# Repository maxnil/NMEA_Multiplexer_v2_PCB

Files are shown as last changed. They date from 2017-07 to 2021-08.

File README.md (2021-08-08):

# NMEA_Multiplexer_v2_PCB
NMEA Multiplexer v2 PCB

Updated version of the old 2010 NMEA Miltiplexer.
This new improved version has support for 5 NMEA interfaces, USB as well as a BlueTooth module.

Firmware for this board is can be found in the https://github.com/maxnil/NMEA_Multiplexer_v2.0_FW repository.

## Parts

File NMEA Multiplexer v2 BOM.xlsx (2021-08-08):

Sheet: Sheet2
Reference | Value | Footprint | DigiKey part number
SW1 | Reset | Buttons_Switches_SMD:SW_SPST_EVQP2 | P12297SCT-ND (http://www.digikey.se/scripts/DkSearch/dksus.dll?Detail&itemSeq=233854998&uq=636362325610804098)
C1 | 0.1u | Capacitors_SMD:C_0603 | 1276-1006-1-ND (http://www.digikey.se/scripts/DkSearch/dksus.dll?Detail&itemSeq=233856982&uq=636362335538323001)
C2 | 0.1u | Capacitors_SMD:C_0603 | 1276-1006-1-ND (http://www.digikey.se/scripts/DkSearch/dksus.dll?Detail&itemSeq=233856982&uq=636362335538323001)
C3 | 0.1u | Capacitors_SMD:C_0603 | 1276-1006-1-ND
C4 | 0.1u | Capacitors_SMD:C_0603 | 1276-1006-1-ND
C5 | 0.1u | Capacitors_SMD:C_0603 | 1276-1006-1-ND
C6 | 0.1u | Capacitors_SMD:C_0603 | 1276-1006-1-ND
C9 | 0.1u | Capacitors_SMD:C_0603 | 1276-1006-1-ND
C10 | 0.1u | Capacitors_SMD:C_0603 | 1276-1006-1-ND
C12 | 0.1u | Capacitors_SMD:C_0603 | 1276-1006-1-ND
C13 | 0.1u | Capacitors_SMD:C_0603 | 1276-1006-1-ND
C15 | 0.1u | Capacitors_SMD:C_0603 | 1276-1006-1-ND
C16 | 0.1u | Capacitors_SMD:C_0603 | 1276-1006-1-ND
C17 | 0.1u | Capacitors_SMD:C_0603 | 1276-1006-1-ND
C18 | 0.1u | Capacitors_SMD:C_0603 | 1276-1006-1-ND
C19 | 0.1u | Capacitors_SMD:C_0603 | 1276-1006-1-ND
C20 | 0.1u | Capacitors_SMD:C_0603 | 1276-1006-1-ND
C21 | 0.1u | Capacitors_SMD:C_0603 | 1276-1006-1-ND
C22 | 0.1u | Capacitors_SMD:C_0603 | 1276-1006-1-ND
C24 | 0.1u | Capacitors_SMD:C_0603 | 1276-1006-1-ND
C26 | 0.1u | Capacitors_SMD:C_0603 | 1276-1006-1-ND
C27 | 0.1u | Capacitors_SMD:C_0603 | 1276-1006-1-ND
C28 | 0.1u | Capacitors_SMD:C_0603 | 1276-1006-1-ND
C29 | 0.1u | Capacitors_SMD:C_0603 | 1276-1006-1-ND
C25 | 2.2u | Capacitors_SMD:C_0603 | 399-7886-1-ND (http://www.digikey.se/scripts/DkSearch/dksus.dll?Detail&itemSeq=233857221&uq=636362336629405848)
C11 | 4.7u | Capacitors_SMD:C_0603 | 1276-1784-1-ND (http://www.digikey.se/scripts/DkSearch/dksus.dll?Detail&itemSeq=233857265&uq=636362336871900095)
C23 | 4.7u | Capacitors_SMD:C_0603 | 1276-1784-1-ND (http://www.digikey.se/scripts/DkSearch/dksus.dll?Detail&itemSeq=233857265&uq=636362336871900095)
C7 | 5p | Capacitors_SMD:C_0603 | 1276-2129-1-ND (http://www.digikey.se/scripts/DkSearch/dksus.dll?Detail&itemSeq=233856961&uq=636362335538313000)
C8 | 5p | Capacitors_SMD:C_0603 | 1276-2129-1-ND (http://www.digikey.se/scripts/DkSearch/dksus.dll?Detail&itemSeq=233856961&uq=636362335538313000)
C14 | 10u | Capacitors_SMD:CP_Elec_4x5.8 | 399-6695-1-ND (http://www.digikey.se/scripts/DkSearch/dksus.dll?Detail&itemSeq=233860772&uq=636362360830165682)
J7 | 12V | Connectors_Terminal_Blocks:TerminalBlock_Pheonix_PT-3.5mm_2pol | ED2740-ND (http://www.digikey.se/scripts/DkSearch/dksus.dll?Detail&itemSeq=233937810&uq=636364126030926649)
J2 | Port 1 | Connectors_Terminal_Blocks:TerminalBlock_Pheonix_PT-3.5mm_3pol | ED2741-ND (http://www.digikey.se/scripts/DkSearch/dksus.dll?Detail&itemSeq=233937812&uq=636364126030936651)
J3 | Port 2 | Connectors_Terminal_Blocks:TerminalBlock_Pheonix_PT-3.5mm_3pol | ED2741-ND (http://www.digikey.se/scripts/DkSearch/dksus.dll?Detail&itemSeq=233937812&uq=636364126030936651)
J4 | Port 3 | Connectors_Terminal_Blocks:TerminalBlock_Pheonix_PT-3.5mm_3pol | ED2741-ND (http://www.digikey.se/scripts/DkSearch/dksus.dll?Detail&itemSeq=233937812&uq=636364126030936651)
J5 | Port 4 | Connectors_Terminal_Blocks:TerminalBlock_Pheonix_PT-3.5mm_3pol | ED2741-ND (http://www.digikey.se/scripts/DkSearch/dksus.dll?Detail&itemSeq=233937812&uq=636364126030936651)
J6 | Port 5 | Connectors_Terminal_Blocks:TerminalBlock_Pheonix_PT-3.5mm_3pol | ED2741-ND (http://www.digikey.se/scripts/DkSearch/dksus.dll?Detail&itemSeq=233937812&uq=636364126030936651)
J1 | USB | Connectors:USB_Mini-B | H2959CT-ND (http://www.digikey.se/scripts/DkSearch/dksus.dll?Detail&itemSeq=233838959&uq=636362305705239991)
Y1 | 32.768k | Crystals:Crystal_SMD_3215-2pin_3.2x1.5mm | 631-1002-1-ND (http://www.digikey.se/scripts/DkSearch/dksus.dll?Detail&itemSeq=233862150&uq=636362369648505753)
U2 | XR32330 | Housings_DFN_QFN:QFN-24_4x4mm_Pitch0.5mm_NoMask | 1016-2177-ND (http://www.digikey.se/scripts/DkSearch/dksus.dll?Detail&itemSeq=233859401&uq=636362352373879101)
U3 | XR32330 | Housings_DFN_QFN:QFN-24_4x4mm_Pitch0.5mm_NoMask | 1016-2177-ND (http://www.digikey.se/scripts/DkSearch/dksus.dll?Detail&itemSeq=233859401&uq=636362352373879101)
U1 | ATSAMG55J19A-AU | Housings_QFP:LQFP-64_10x10mm_Pitch0.5mm | 1611-ATSAMG55J19A-AUTCT-ND (http://www.digikey.se/scripts/DkSearch/dksus.dll?Detail&itemSeq=233859668&uq=636362353992571220)
D8 | BT Con (blue) | LEDs:LED_0603 | 475-2815-1-ND (http://www.digikey.se/scripts/DkSearch/dksus.dll?Detail&itemSeq=233851496&uq=636362305705279995)
D18 | Err 0 (red) | LEDs:LED_0603 | 511-1586-1-ND (http://www.digikey.se/scripts/DkSearch/dksus.dll?Detail&itemSeq=233851438&uq=636362305705259993)
D15 | Err 1 (red) | LEDs:LED_0603 | 511-1586-1-ND (http://www.digikey.se/scripts/DkSearch/dksus.dll?Detail&itemSeq=233851438&uq=636362305705259993)
D12 | Err 2 (red) | LEDs:LED_0603 | 511-1586-1-ND (http://www.digikey.se/scripts/DkSearch/dksus.dll?Detail&itemSeq=233851438&uq=636362305705259993)
D2 | Err 3 (red) | LEDs:LED_0603 | 511-1586-1-ND
D5 | Err 4 (red) | LEDs:LED_0603 | 511-1586-1-ND
D7 | PWR (white) | LEDs:LED_0603 | 511-1602-1-ND (http://www.digikey.se/scripts/DkSearch/dksus.dll?Detail&itemSeq=233851586&uq=636362305705289996)
D19 | Rx 0 (green) | LEDs:LED_0603 | 511-1584-1-ND (http://www.digikey.se/scripts/DkSearch/dksus.dll?Detail&itemSeq=233851423&uq=636362305705249992)
D16 | Rx 1 (green) | LEDs:LED_0603 | 511-1584-1-ND (http://www.digikey.se/scripts/DkSearch/dksus.dll?Detail&itemSeq=233851423&uq=636362305705249992)
D13 | Rx 2 (green) | LEDs:LED_0603 | 511-1584-1-ND
D3 | Rx 3 (green) | LEDs:LED_0603 | 511-1584-1-ND
D6 | Rx 4 (green) | LEDs:LED_0603 | 511-1584-1-ND
D10 | Rx BT (green) | LEDs:LED_0603 | 511-1584-1-ND
D11 | Tx (green) | LEDs:LED_0603 | 511-1584-1-ND
D17 | Tx 0 (green) | LEDs:LED_0603 | 511-1584-1-ND
D14 | Tx 1 (green) | LEDs:LED_0603 | 511-1584-1-ND
D1 | Tx 3 (green) | LEDs:LED_0603 | 511-1584-1-ND
D4 | Tx 4 (green) | LEDs:LED_0603 | 511-1584-1-ND
D9 | Tx BT (green) | LEDs:LED_0603 | 511-1584-1-ND
U5 | HM-11 | MaxNil:HM-11 | n/a
JP1 | ERASE | Pin_Headers:Pin_Header_Straight_1x02_Pitch2.00mm | 952-2326-ND (http://www.digikey.se/scripts/DkSearch/dksus.dll?Detail&itemSeq=233938101&uq=636364129656245809)
J8 | DEBUG UART | Pin_Headers:Pin_Header_Straight_1x03_Pitch2.54mm | S1011EC-40-ND (http://www.digikey.se/scripts/DkSearch/dksus.dll?Detail&itemSeq=233938745&uq=636364143898009148)
J9 | JTAG | Pin_Headers:Pin_Header_Straight_2x05_Pitch1.27mm_SMD | 609-3741-ND (http://www.digikey.se/scripts/DkSearch/dksus.dll?Detail&itemSeq=233858132&uq=636362343783641200)
R10 | 39 | Resistors_SMD:R_0603 | 311-39.0HRCT-ND (http://www.digikey.se/scripts/DkSearch/dksus.dll?Detail&itemSeq=233862991&uq=636362373801941220)
R12 | 39 | Resistors_SMD:R_0603 | 311-39.0HRCT-ND (http://www.digikey.se/scripts/DkSearch/dksus.dll?Detail&itemSeq=233862991&uq=636362373801941220)
R16 | 39 | Resistors_SMD:R_0603 | 311-39.0HRCT-ND (http://www.digikey.se/scripts/DkSearch/dksus.dll?Detail&itemSeq=233862991&uq=636362373801941220)
R17 | 39 | Resistors_SMD:R_0603 | 311-39.0HRCT-ND (http://www.digikey.se/scripts/DkSearch/dksus.dll?Detail&itemSeq=233862991&uq=636362373801941220)
R13 | 120 | Resistors_SMD:R_0603
R1 | 220 | Resistors_SMD:R_0603 | 311-220HRCT-ND (http://www.digikey.se/scripts/DkSearch/dksus.dll?Detail&itemSeq=233862888&uq=636362373801931220)
R2 | 220 | Resistors_SMD:R_0603 | 311-220HRCT-ND
R3 | 220 | Resistors_SMD:R_0603 | 311-220HRCT-ND
R4 | 220 | Resistors_SMD:R_0603 | 311-220HRCT-ND
R5 | 220 | Resistors_SMD:R_0603 | 311-220HRCT-ND
R6 | 220 | Resistors_SMD:R_0603 | 311-220HRCT-ND
R7 | 220 | Resistors_SMD:R_0603 | 311-220HRCT-ND
R8 | 220 | Resistors_SMD:R_0603 | 311-220HRCT-ND
R18 | 220 | Resistors_SMD:R_0603 | 311-220HRCT-ND
R19 | 220 | Resistors_SMD:R_0603 | 311-220HRCT-ND
R20 | 220 | Resistors_SMD:R_0603 | 311-220HRCT-ND
R21 | 220 | Resistors_SMD:R_0603 | 311-220HRCT-ND
R22 | 220 | Resistors_SMD:R_0603 | 311-220HRCT-ND
R23 | 220 | Resistors_SMD:R_0603 | 311-220HRCT-ND
R27 | 220 | Resistors_SMD:R_0603 | 311-220HRCT-ND
R28 | 220 | Resistors_SMD:R_0603 | 311-220HRCT-ND
R29 | 220 | Resistors_SMD:R_0603 | 311-220HRCT-ND
R9 | 82 | Resistors_SMD:R_0603 | 311-82.0HRCT-ND (http://www.digikey.se/scripts/DkSearch/dksus.dll?Detail&itemSeq=233862972&uq=636362373801931220)
R11 | 100k | Resistors_SMD:R_0603 | 311-100KHRCT-ND (http://www.digikey.se/scripts/DkSearch/dksus.dll?Detail&itemSeq=233862853&uq=636362373801921220)
R24 | 100k | Resistors_SMD:R_0603 | 311-100KHRCT-ND (http://www.digikey.se/scripts/DkSearch/dksus.dll?Detail&itemSeq=233862853&uq=636362373801921220)
R25 | 100k | Resistors_SMD:R_0603 | 311-100KHRCT-ND
R26 | 100k | Resistors_SMD:R_0603 | 311-100KHRCT-ND
R14 | 27k | Resistors_SMD:R_0603 | 311-27.0KHRCT-ND (http://www.digikey.se/scripts/DkSearch/dksus.dll?Detail&itemSeq=233862921&uq=636362373801931220)
R15 | 47k | Resistors_SMD:R_0603 | 311-47.0KHRCT-ND (http://www.digikey.se/scripts/DkSearch/dksus.dll?Detail&itemSeq=233862873&uq=636362373801921220)
U4 | LF33ABDT-TR | TO_SOT_Packages_SMD:TO-252-2_Rectifier | 497-5225-1-ND (http://www.digikey.se/scripts/DkSearch/dksus.dll?Detail&itemSeq=233863143&uq=636362374865240887)

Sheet: Sheet1
Reference | Value | Footprint | Datasheet
U1 | ATSAMG55J19A-AU | Housings_QFP:LQFP-64_10x10mm_Pitch0.5mm
Y1 | 32.768k | Crystals:Crystal_SMD_3215-2pin_3.2x1.5mm
C8 | 5n | Capacitors_SMD:C_0603
C7 | 5n | Capacitors_SMD:C_0603
J1 | USB | Connectors:USB_Mini-B
J9 | JTAG | Pin_Headers:Pin_Header_Straight_2x05_Pitch1.27mm_SMD
R24 | 100k | Resistors_SMD:R_0603
R25 | 100k | Resistors_SMD:R_0603
R26 | 100k | Resistors_SMD:R_0603
JP1 | ERASE | Pin_Headers:Pin_Header_Straight_1x02_Pitch2.00mm
R16 | 39 | Resistors_SMD:R_0603
R17 | 39 | Resistors_SMD:R_0603
D18 | Err 0 (red) | LEDs:LED_0603
R27 | 220 | Resistors_SMD:R_0603
R28 | 220 | Resistors_SMD:R_0603
R29 | 220 | Resistors_SMD:R_0603
D17 | Tx 0 (green) | LEDs:LED_0603
D19 | Rx 0 (green) | LEDs:LED_0603
D15 | Err 1 (red) | LEDs:LED_0603
R21 | 220 | Resistors_SMD:R_0603
R23 | 220 | Resistors_SMD:R_0603
R22 | 220 | Resistors_SMD:R_0603
D14 | Tx 1 (green) | LEDs:LED_0603
D16 | Rx 1 (green) | LEDs:LED_0603
D12 | Err 2 (red) | LEDs:LED_0603
R19 | 220 | Resistors_SMD:R_0603
R18 | 220 | Resistors_SMD:R_0603
R20 | 220 | Resistors_SMD:R_0603
D11 | Tx (green) | LEDs:LED_0603
D13 | Rx 2 (green) | LEDs:LED_0603
D2 | Err 3 (red) | LEDs:LED_0603
R1 | 220 | Resistors_SMD:R_0603
R3 | 220 | Resistors_SMD:R_0603
R2 | 220 | Resistors_SMD:R_0603
D1 | Tx 3 (green) | LEDs:LED_0603
D3 | Rx 3 (green) | LEDs:LED_0603
D5 | Err 4 (red) | LEDs:LED_0603
R5 | 220 | Resistors_SMD:R_0603
R4 | 220 | Resistors_SMD:R_0603
R6 | 220 | Resistors_SMD:R_0603
D4 | Tx 4 (green) | LEDs:LED_0603
D6 | Rx 4 (green) | LEDs:LED_0603
R7 | 220 | Resistors_SMD:R_0603
R8 | 220 | Resistors_SMD:R_0603
D9 | Tx BT (green) | LEDs:LED_0603
D10 | Rx BT (green) | LEDs:LED_0603
D8 | BT Con (blue) | LEDs:LED_0603
R13 | 220 | Resistors_SMD:R_0603
J8 | DEBUG UART | Pin_Headers:Pin_Header_Straight_1x03_Pitch2.54mm
D7 | PWR (green) | LEDs:LED_0603
R9 | 220 | Resistors_SMD:R_0603
R14 | 27k | Resistors_SMD:R_0603
R15 | 47k | Resistors_SMD:R_0603
SW1 | Reset | Buttons_Switches_SMD:SW_SPST_EVQP2
R12 | 39 | Resistors_SMD:R_0603
R10 | 39 | Resistors_SMD:R_0603
R11 | 100k | Resistors_SMD:R_0603
U3 | XR32330 | Housings_DFN_QFN:QFN-24_4x4mm_Pitch0.5mm_NoMask
U2 | XR32330 | Housings_DFN_QFN:QFN-24_4x4mm_Pitch0.5mm_NoMask
J2 | Port 1 | Connectors_Terminal_Blocks:TerminalBlock_Pheonix_PT-3.5mm_3pol
J3 | Port 2 | Connectors_Terminal_Blocks:TerminalBlock_Pheonix_PT-3.5mm_3pol
J4 | Port 3 | Connectors_Terminal_Blocks:TerminalBlock_Pheonix_PT-3.5mm_3pol
J5 | Port 4 | Connectors_Terminal_Blocks:TerminalBlock_Pheonix_PT-3.5mm_3pol
J6 | Port 5 | Connectors_Terminal_Blocks:TerminalBlock_Pheonix_PT-3.5mm_3pol
J7 | 12V | Connectors_Terminal_Blocks:TerminalBlock_Pheonix_PT-3.5mm_2pol
U4 | LF33ABDT-TR | TO_SOT_Packages_SMD:TO-252-2_Rectifier
C14 | 10u | Capacitors_SMD:CP_Elec_4x5.8
C15 | 100n | Capacitors_SMD:C_0603
C13 | 100n | Capacitors_SMD:C_0603
C29 | 100n | Capacitors_SMD:C_0603
C9 | 100n | Capacitors_SMD:C_0603
C25 | 2.2u | Capacitors_SMD:C_0603
C26 | 100n | Capacitors_SMD:C_0603
C23 | 4.7u | Capacitors_SMD:C_0603
C24 | 100n | Capacitors_SMD:C_0603
C12 | 100n | Capacitors_SMD:C_0603
C11 | 4.7u | Capacitors_SMD:C_0603
C10 | 100n | Capacitors_SMD:C_0603
C27 | 100n | Capacitors_SMD:C_0603
C28 | 100n | Capacitors_SMD:C_0603
C22 | 100n | Capacitors_SMD:C_0603
U5 | HM-11 | MaxNil:HM-11
C1 | 100n | Capacitors_SMD:C_0603
C2 | 100n | Capacitors_SMD:C_0603
C16 | 100n | Capacitors_SMD:C_0603
C17 | 100n | Capacitors_SMD:C_0603
C6 | 100n | Capacitors_SMD:C_0603
C4 | 100n | Capacitors_SMD:C_0603
C3 | 100n | Capacitors_SMD:C_0603
C5 | 100n | Capacitors_SMD:C_0603
C21 | 100n | Capacitors_SMD:C_0603
C19 | 100n | Capacitors_SMD:C_0603
C18 | 100n | Capacitors_SMD:C_0603
C20 | 100n | Capacitors_SMD:C_0603

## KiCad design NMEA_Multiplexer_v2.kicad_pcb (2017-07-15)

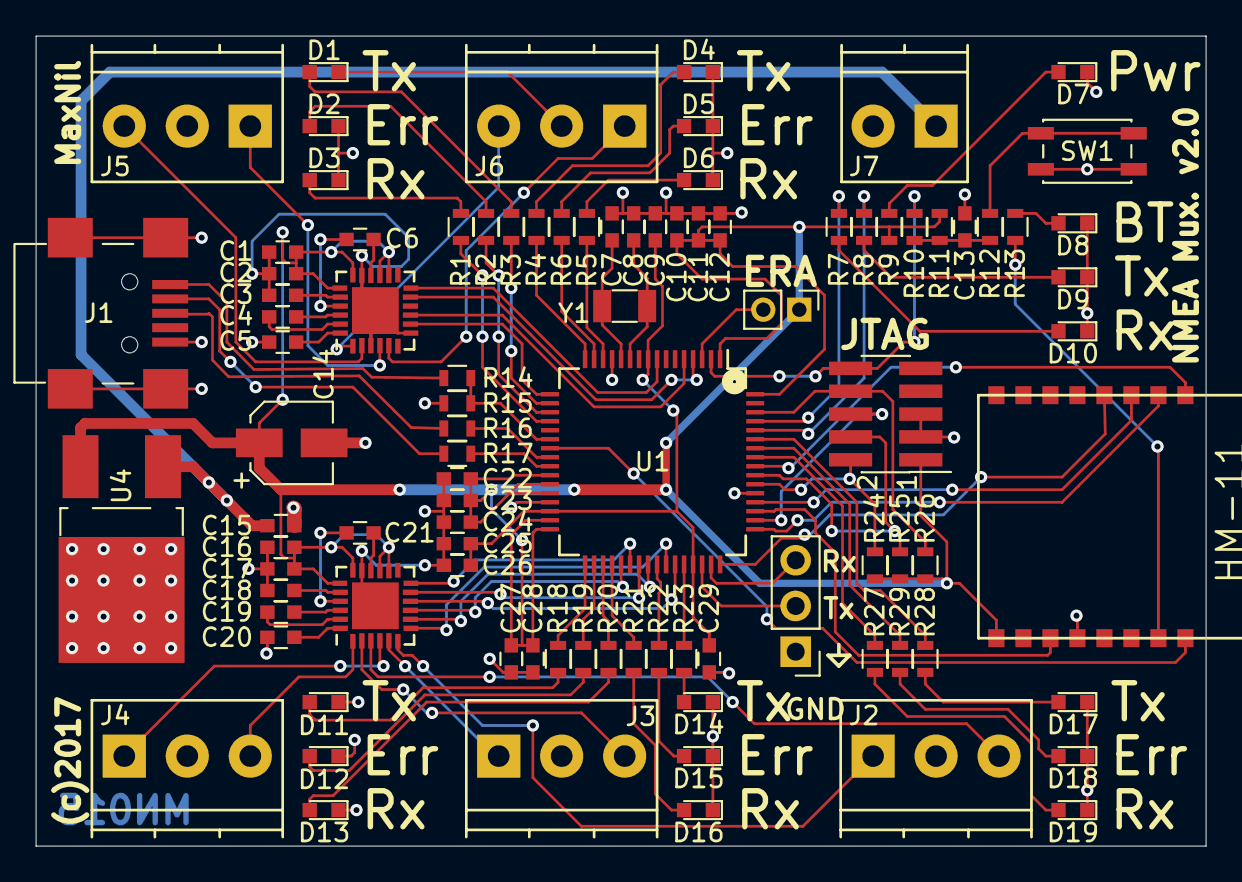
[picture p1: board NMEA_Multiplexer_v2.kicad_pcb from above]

Board: 2 copper layers, 65.0 x 45.0 mm, 94 parts (0 on the bottom side), 97 nets.

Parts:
C1, C2, C3, C4, C5, C6, C9, C10, C12, C13, C15, C16, C17, C18, C19, C20, C21, C22, C24, C26, C27, C28, C29: 100n; C_0603
C7, C8: 5n; C_0603
C11, C23: 4.7u; C_0603
C14: 10u; CP_Elec_4x5.8
C25: 2.2u; C_0603
D1: Tx 3 (green); LED_0603
D2: Err 3 (red); LED_0603
D3: Rx 3 (green); LED_0603
D4: Tx 4 (green); LED_0603
D5: Err 4 (red); LED_0603
D6: Rx 4 (green); LED_0603
D7: PWR (green); LED_0603
D8: BT Con (blue); LED_0603
D9: Tx BT (green); LED_0603
D10: Rx BT (green); LED_0603
D11: Tx (green); LED_0603
D12: Err 2 (red); LED_0603
D13: Rx 2 (green); LED_0603
D14: Tx 1 (green); LED_0603
D15: Err 1 (red); LED_0603
D16: Rx 1 (green); LED_0603
D17: Tx 0 (green); LED_0603
D18: Err 0 (red); LED_0603
D19: Rx 0 (green); LED_0603
J1: USB; USB_Mini-B_UX60-MB-5ST
J2: Port 1; TerminalBlock_Pheonix_PT-3.5mm_3pol
J3: Port 2; TerminalBlock_Pheonix_PT-3.5mm_3pol
J4: Port 3; TerminalBlock_Pheonix_PT-3.5mm_3pol
J5: Port 4; TerminalBlock_Pheonix_PT-3.5mm_3pol
J6: Port 5; TerminalBlock_Pheonix_PT-3.5mm_3pol
J7: 12V; TerminalBlock_Pheonix_PT-3.5mm_2pol
J8: DEBUG UART; Pin_Header_Straight_1x03_Pitch2.54mm
J9: JTAG; Pin_Header_Straight_2x05_Pitch1.27mm_SMD
JP1: ERASE; Pin_Header_Straight_1x02_Pitch2.00mm
R1, R2, R3, R4, R5, R6, R7, R8, R9, R13, R18, R19, R20, R21, R22, R23, R27, R28, R29: 220; R_0603
R10, R12, R16, R17: 39; R_0603
R11, R24, R25, R26: 100k; R_0603
R14: 27k; R_0603
R15: 47k; R_0603
SW1: Reset; SW_SPST_EVQP2
U1: ATSAMG55J19A-AU; LQFP-64_10x10mm_Pitch0.5mm
U2, U3: XR32330; QFN-24_4x4mm_Pitch0.5mm_NoMask
U4: LF33ABDT-TR; TO-252-2_Rectifier
U5: HM-11
Y1: 32.768k; Crystal_SMD_3215-2pin_3.2x1.5mm

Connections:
+1V8: C9.1, C25.1, C26.1, C29.1, U1.9, U1.30, U1.45
+3V3: C1.1, C2.1, C10.1, C11.1, C12.1, C14.1, C16.1, C17.1, C22.1, C23.1, C24.1, C27.1, C28.1, J9.1, JP1.1, R9.1, R11.1, R24.1, R25.1, R26.1, U1.1, U1.26, U1.27, U1.28, U1.31, U1.32, U1.64, U2.14, U2.15, U2.18, U2.19, U3.14, U3.15, U3.18, U3.19, U4.3, U5.9
/BT_KEY: U1.23, U5.16
/BT_RESET_N: U1.51, U5.11
/CTS0: U1.56, U5.1
/DM: R17.1, U1.25
/DP: R16.1, U1.24
/LED_0_ERR: R29.1, U1.58
/LED_0_RX: R27.1, U1.57
/LED_0_TX: R28.1, U1.59
/LED_1_ERR: R22.1, U1.41
/LED_1_RX: R21.1, U1.36
/LED_1_TX: R23.1, U1.44
/LED_2_ERR: R19.1, U1.34
/LED_2_RX: R20.1, U1.35
/LED_2_TX: R18.1, U1.33
/LED_3_ERR: R2.1, U1.19
/LED_3_RX: R1.1, U1.20
/LED_3_TX: R3.1, U1.18
/LED_4_ERR: R6.1, U1.15
/LED_4_RX: R5.1, U1.14
/LED_4_TX: R4.1, U1.16
/LED_BT_CON: R13.1, U5.15
/LED_BT_RX: R7.1, U1.61
/LED_BT_TX: R8.1, U1.60
/RTS0: U1.52, U5.3
/RX0: J2.3, U3.3
/RX1: J3.3, U3.2
/RX2: J4.3, U3.1
/RX3: J5.3, U2.2
/RX4: J6.3, U2.1
/RXD0: U1.49, U5.2
/RXD1: U1.39, U3.11
/RXD2: U1.8, U2.12
/RXD3: U1.4, U2.11
/RXD4: J8.3, U1.47
/RXD5: U1.43, U3.10
/RXD6: U1.38, U3.12
/TCK: J9.4, R25.2, U1.55
/TDI: J9.8, R26.2, U1.62
/TDO: J9.6, U1.50
/TMS: J9.2, R24.2, U1.54
/TX0: J2.1, U3.6
/TX1: J3.1, U3.5
/TX2: J4.1, U3.4
/TX3: J5.1, U2.4
/TX4: J6.1, U2.5
/TXD0: U1.48, U5.4
/TXD1: U1.40, U3.8
/TXD2: U1.17, U2.8
/TXD3: U1.5, U2.9
/TXD4: J8.2, U1.46
/TXD5: U1.42, U3.7
/TXD6: U1.37, U3.9
/VBUS_3.3V: R14.2, R15.1, U1.22
/XIN32: C8.1, U1.11, Y1.1
/XOUT32: C7.1, U1.12, Y1.2
/nRST: J9.10, R10.1, U1.2
GND: C1.2, C2.2, C3.1, C5.1, C7.2, C8.2, C9.2, C10.2, C11.2, C12.2, C13.2, C14.2, C15.2, C16.2, C17.2, C18.1, C20.1, C22.2, C23.2, C24.2, C25.2, C26.2, C27.2, C28.2, C29.2, D1.1, D2.1, D3.1, D4.1, D5.1, D6.1, D7.1, D8.1, D9.1, D10.1, D11.1, D12.1, D13.1, D14.1, D15.1, D16.1, D17.1, D18.1, D19.1, J1.5, J1.6, J2.2, J3.2, J4.2, J5.2, J6.2, J7.2, J8.1, J9.3, J9.5, R15.2, SW1.1, U1.13, U1.29, U1.53, U2.3, U2.7, U2.17, U2.25, U3.17, U3.25, U4.2, U5.12
unnamed: C3.2, U2.20
unnamed: C4.1, U2.22
unnamed: C4.2, U2.23
unnamed: C5.2, U2.24
unnamed: C6.1, U2.21
unnamed: C6.2, U2.16
unnamed: C13.1, R10.2, R11.2, R12.1
unnamed: C15.1, J7.1, U4.1
unnamed: C18.2, U3.20
unnamed: C19.1, U3.22
unnamed: C19.2, U3.23
unnamed: C20.2, U3.24
unnamed: C21.1, U3.21
unnamed: C21.2, U3.16
unnamed: D1.2, R3.2
unnamed: D2.2, R2.2
unnamed: D3.2, R1.2
unnamed: D4.2, R4.2
unnamed: D5.2, R6.2
unnamed: D6.2, R5.2
unnamed: D7.2, R9.2
unnamed: D8.2, R13.2
unnamed: D9.2, R8.2
unnamed: D10.2, R7.2
unnamed: D11.2, R18.2
unnamed: D12.2, R19.2
unnamed: D13.2, R20.2
unnamed: D14.2, R23.2
unnamed: D15.2, R22.2
unnamed: D16.2, R21.2
unnamed: D17.2, R28.2
unnamed: D18.2, R29.2
unnamed: D19.2, R27.2
unnamed: J1.1, R14.1
unnamed: J1.2, R17.2
unnamed: J1.3, R16.2
unnamed: JP1.2, U1.3
unnamed: R12.2, SW1.2

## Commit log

2017-04-17 First version
    [NMEA_Multiplexer_v2.kicad_pcb, NMEA_Multiplexer_v2.sch]
2017-05-04 First complete schematic
    [NMEA_Multiplexer_v2.kicad_pcb, NMEA_Multiplexer_v2.sch]
2017-05-04 Fixed some pin-errors in the ATSAM symbol Swapped place between LED and resistor
    [NMEA_Multiplexer_v2.sch]
2017-05-09 Schematic ok Most of components placed on PCB
    [NMEA_Multiplexer_v2.kicad_pcb, NMEA_Multiplexer_v2.sch]
2017-05-14 Before the renaming
    [NMEA_Multiplexer_v2.kicad_pcb, NMEA_Multiplexer_v2.sch]
2017-05-20 Fixed missing decaps on VDDCORE
    [NMEA_Multiplexer_v2.sch]
2017-05-20 Placement complete
    [NMEA_Multiplexer_v2.kicad_pcb]
2017-05-25 Swapped LED_BT_TX with LED_BT_RX
2017-05-25 Bottom half completed
    [NMEA_Multiplexer_v2.kicad_pcb]
2017-06-08 Swapped values between C11 and C12
    [NMEA_Multiplexer_v2.sch]
2017-06-08 More connections
    [NMEA_Multiplexer_v2.kicad_pcb]
2017-07-08 Soon complete
    [NMEA_Multiplexer_v2.kicad_pcb, NMEA_Multiplexer_v2.sch]
2017-07-11 Everything connected!
    [NMEA_Multiplexer_v2.kicad_pcb, NMEA_Multiplexer_v2.sch]
2017-07-12 Added copyright and board text
    [NMEA_Multiplexer_v2.kicad_pcb]
2017-07-12 First version of the Gerber files
    [NMEA_Multiplexer_v2-B.Cu.gbr, NMEA_Multiplexer_v2-B.Mask.gbr, NMEA_Multiplexer_v2-Edge.Cuts.gbr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]
2017-07-15 Updated USB footprint Connected BT KEY pin
    [NMEA_Multiplexer_v2-B.Cu.gbr, NMEA_Multiplexer_v2-B.Mask.gbr, NMEA_Multiplexer_v2-Edge.Cuts.gbr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]

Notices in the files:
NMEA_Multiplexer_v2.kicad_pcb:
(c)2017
